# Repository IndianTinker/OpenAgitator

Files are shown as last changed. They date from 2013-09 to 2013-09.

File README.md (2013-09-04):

OpenAgitator
============

http://wp.me/p1C1sd-7Q

The support files for making your own OpenAgitator.

It includes the firmware files for MSP430 compiled in CCS on windows.
The hardware files are included which include the schematic and board layout designed in Eagle 6.4 and hence 
are not compatible with lower versions.

Happy Tinkering!

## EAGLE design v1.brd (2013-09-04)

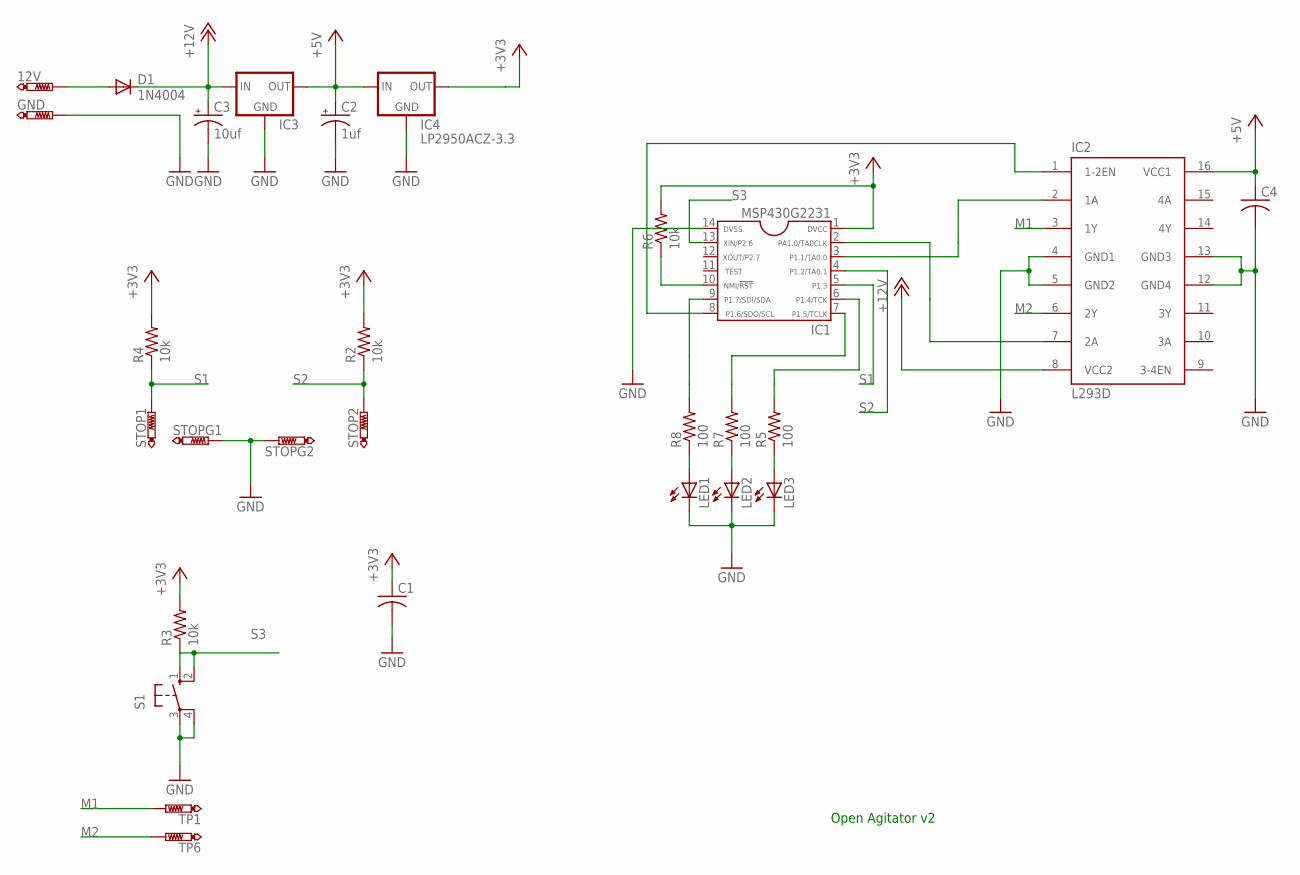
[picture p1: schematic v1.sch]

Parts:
12V: PTR1PAD1-13Y; P1-13Y
C1, C4: CAP0805; C0805
C2: 1uf; E2,5-6E
C3: 10uf; E2,5-6E
D1: 1N4004; DO41-10
GND: PTR1PAD1-13Y; P1-13Y
IC1: MSP430G2231; DIP14
IC2: L293D; DIL16
IC3: V_REG_78XX-TO-220; TO-220-ALT
IC4: LP2950ACZ-3.3; TO92
LED1, LED2, LED3: LED5MM
R2: 10k; 0207/10
R3, R4, R6: 10k; 0207/7
R5, R7: 100; 0207/7
R8: 100; 0207/10
S1: 10-XX; B3F-10XX
STOP1, STOP2: PTR1PAD1-13Y; P1-13Y
STOPG1, STOPG2: PTR1PAD1-13Y; P1-13Y
TP1, TP6: PTR1PAD1-13Y; P1-13Y

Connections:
+3V3: C1.1, IC1.1, IC4.1 (OUT), R2.2, R3.2, R4.2, R6.2
+5V: C2.+, C4.1, IC2.16 (VCC1), IC3.OUT, IC4.3 (IN)
+12V: C3.+, D1.C, IC2.8 (VCC2), IC3.IN
GND: C1.2, C2.-, C3.-, C4.2, GND.TP, IC1.14, IC2.4 (GND1), IC2.5 (GND2), IC2.12 (GND4), IC2.13 (GND3), IC3.GND, IC4.2 (GND), LED1.K (C), LED2.K (C), LED3.K (C), S1.3, S1.4 (P1), STOPG1.TP, STOPG2.TP
M1: IC2.3 (1Y), TP1.TP
M2: IC2.6 (2Y), TP6.TP
unnamed: IC1.8, IC2.1 (1-2EN)
unnamed: IC1.3, IC2.2 (1A)
unnamed: 12V.TP, D1.A
unnamed: IC1.2, IC2.7 (2A)
unnamed: IC1.10, R6.1
unnamed: IC1.7, R7.2
unnamed: IC1.6, R5.2
unnamed: IC1.9, R8.2
unnamed: LED1.A, R8.1
unnamed: LED2.A, R7.1
unnamed: LED3.A, R5.1
S1: IC1.5, R4.1, STOP1.TP
S2: IC1.4, R2.1, STOP2.TP
S3: IC1.13, R3.1, S1.1 (S), S1.2 (S1)

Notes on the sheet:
Open Agitator v2

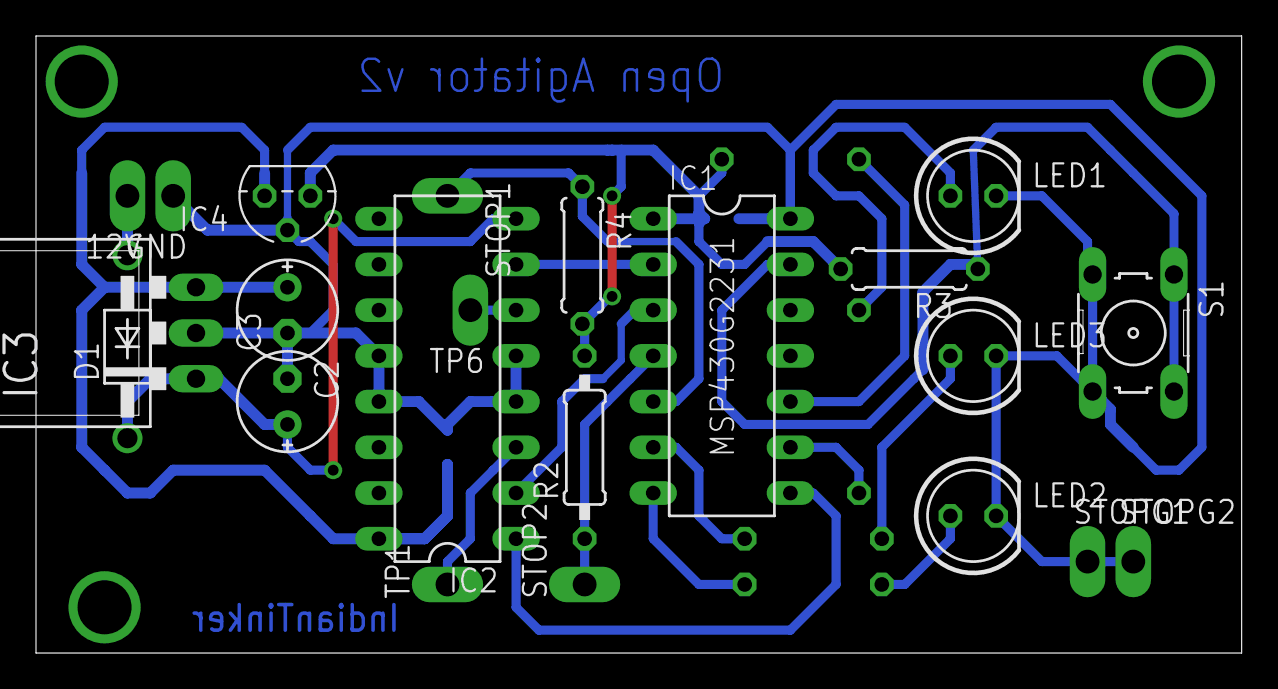
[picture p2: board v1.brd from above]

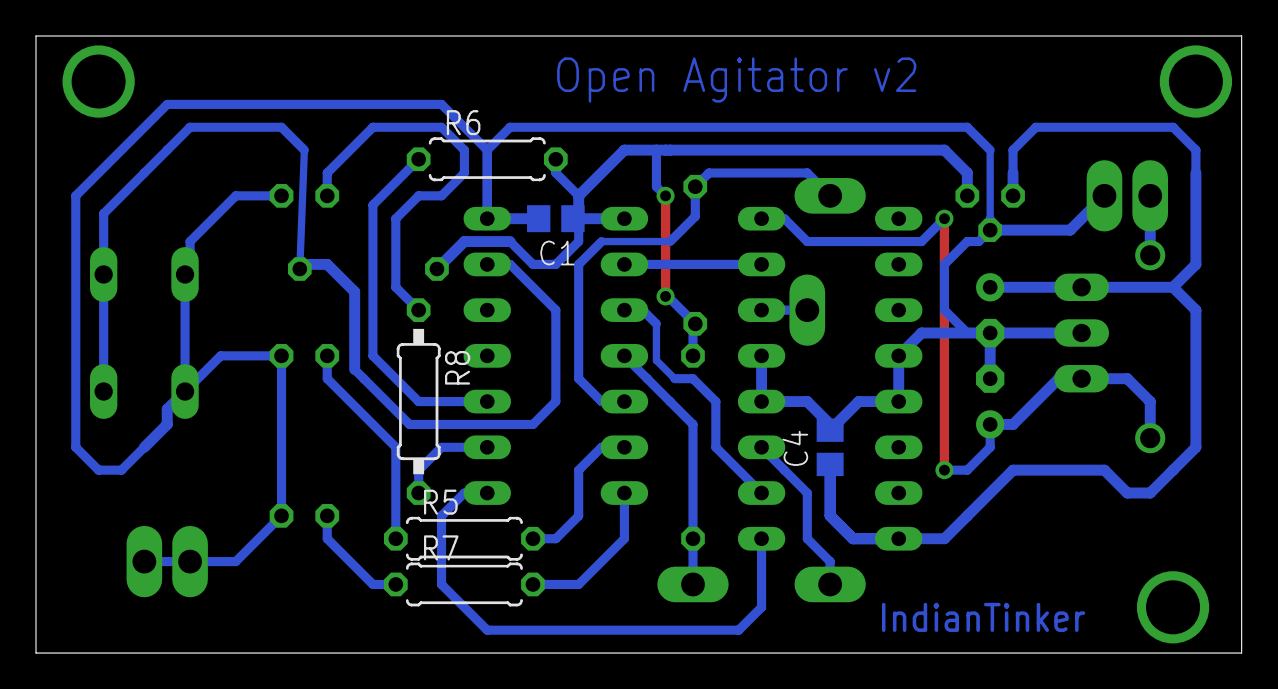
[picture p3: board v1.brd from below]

Board: 2 copper layers, 67.0 x 34.3 mm, 28 parts (6 on the bottom side), 20 nets.

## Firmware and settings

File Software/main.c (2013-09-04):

/*
Open Agitator v2
author: Rohit Gupta
email:  rohit7gupta at gmail dot com

homepage: www.indiantinker.wordpress.com

compiler: Code Composer Studio


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
You should have received a copy of the GNU General Public License
along with this program.  If not, see <http://www.gnu.org/licenses/>.
*/
#include<msp430g2231.h>
#define A1 BIT0
#define A2 BIT1
#define SWC BIT6
#define EN BIT6
#define LED3 BIT7
#define LED2 BIT4
#define LED1 BIT5
#define ES BIT2
void setmode(int val)
{
	if ( (val>=3000) && (val<5000) )
	{   P1OUT&=~(LED1+LED2+LED3);
		P1OUT|=LED1;
	}
	else if ((val>=5000) && (val<=7500))
	{
		P1OUT&=~(LED1+LED2+LED3);
		P1OUT|=(LED1+LED2);
	}
	else if(val>7500)
	{
		P1OUT|=(LED1+LED2+LED3);

	}
}
void move()
{

		P1OUT&=~(A1+A2); //STOP
		__delay_cycles(1000);

		P1OUT|=A1;   //down
		P1OUT&=~A2;
		__delay_cycles(340000); // This controls the horizontal travel of the CDROM Cradle
		P1OUT&=~(A1+A2);
		__delay_cycles(1000);

		P1OUT&=~(A1+A2); //STOP
		__delay_cycles(1000);

		P1OUT|=A2;   //up
		P1OUT&=~A1;


}
void main()
{
	WDTCTL = WDTPW + WDTHOLD;      //Stop our Personal Watchdog

	BCSCTL1 = CALBC1_1MHZ;         //Run at 1Mhz
	DCOCTL = CALDCO_1MHZ;

	P1OUT&=~(LED1+LED2+LED3);               //GPIO Config
	P1DIR|=(A1+A2+EN+LED1+LED2+LED3);
	P1SEL|=EN;  //PWM output
    P2SEL&=~SWC;                           // P2.6 is special u see


    P2DIR&=~SWC; //switch as input
	P2IE|=SWC;  //interrupt enable on switch
    P2IFG&=~SWC; //clear interrupt flag for interrupt to proceed
	P2REN|=SWC;
	P2OUT|=SWC;

	P1DIR&=~ES;
	P1IE|=ES;  //interrupt enable on switch
	P1IFG&=~ES; //clear interrupt flag for interrupt to proceed
	P1REN|=ES;
	P1OUT|=ES;
	
	CCR0 = 10000;             // PWM Period
	CCTL1 = OUTMOD_7;          // CCR1 reset/set
    CCR1 = 1000;                // CCR1 PWM duty cycle
    TACTL = TASSEL_2 + MC_1;   // SMCLK, up mode

    _bis_SR_register(GIE); //Global Interrupts enabled

    P1OUT|=A2;   //up until u generate an interrupt
    P1OUT&=~A1;

    while(1)
	{
                //Do nothing
	}
}

#pragma vector=PORT2_VECTOR  //ISR Sub-routine
__interrupt void Port_2(void)
{
	if(P2IFG&SWC)              // When that button is pressed
	{
	P1OUT&=~(A1+A2);           //Stop cradle

	CCR1+=500;                 //Increase Duty
	if(CCR1==10000)            //Check: It doesnt overflow
		{
		CCR1=9500;
		}
	__delay_cycles(100000);    //Wait a bit. Mechanical time constants are larger
	setmode(CCR1);             // Light up the LED
	P1OUT|=A2;   //up           // Go up again and generate an interrupt
	P1OUT&=~A1;

	}
	P2IFG&=~SWC;	 //clear flag

}
#pragma vector=PORT1_VECTOR  //ISR Sub-routine
__interrupt void Port_1(void)
{
	if(P1IFG&ES)
	{
	//When end stop comes then move forward for 1.5sec
	//and then move backward until the next end stop.

		move();

	}
	P1IFG&=~ES;

}

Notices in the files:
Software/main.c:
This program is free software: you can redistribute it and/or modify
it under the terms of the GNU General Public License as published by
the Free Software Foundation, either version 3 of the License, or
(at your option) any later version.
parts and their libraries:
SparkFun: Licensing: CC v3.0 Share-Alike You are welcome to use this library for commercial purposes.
